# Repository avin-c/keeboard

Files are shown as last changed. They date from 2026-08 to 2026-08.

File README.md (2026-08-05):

# Keeboard
my custom 65% mechanical keyboard

total time spent: 12.75 hours

## Bill Of Materials 

| Item  | Quanity | Cost | Source |
| --- | --- | -- | -- |
|  15mm x 1.5mm Rubber Pads | 4  | $3.89 | [AliExpress](https://www.aliexpress.com/item/1005009215190070.html) |
| Content Cell  | Content Cell  | -- | -- |

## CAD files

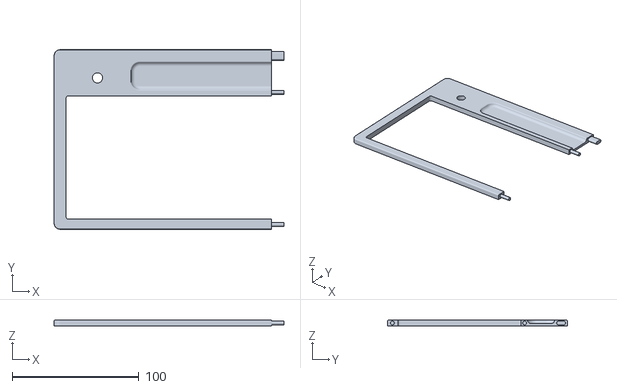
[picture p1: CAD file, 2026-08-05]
keeb-3d-files/top-left-case.stl
181.5 x 141.8 x 5.00

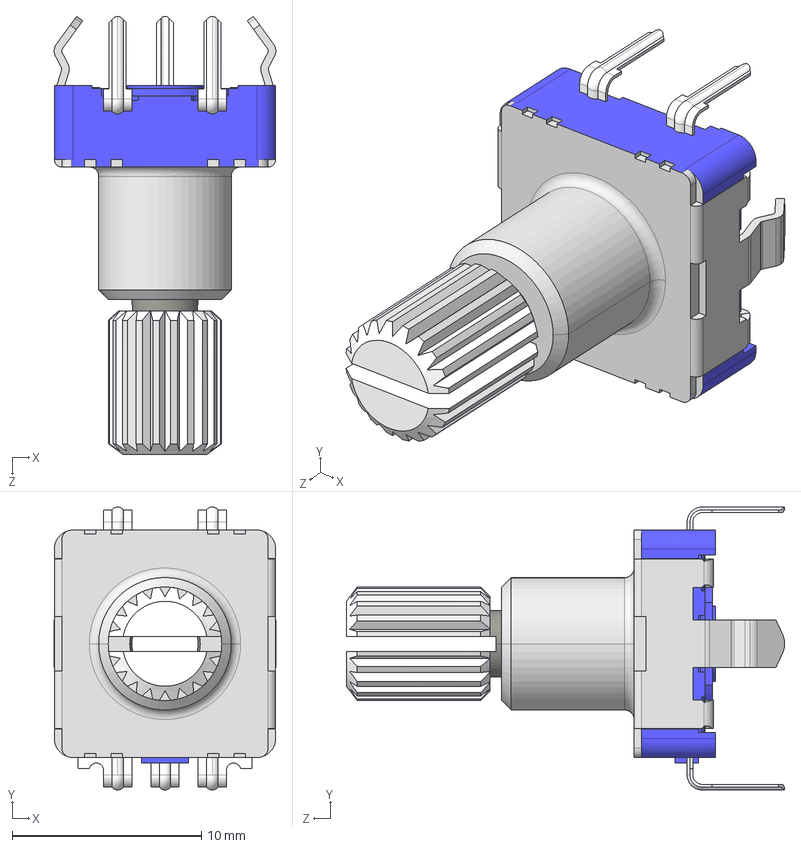
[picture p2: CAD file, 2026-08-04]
keeb-kicad/Assets/EC11 Rotary Encoder Dode Switch-15mm .STEP
11.7 x 15.0 x 23.2 mm

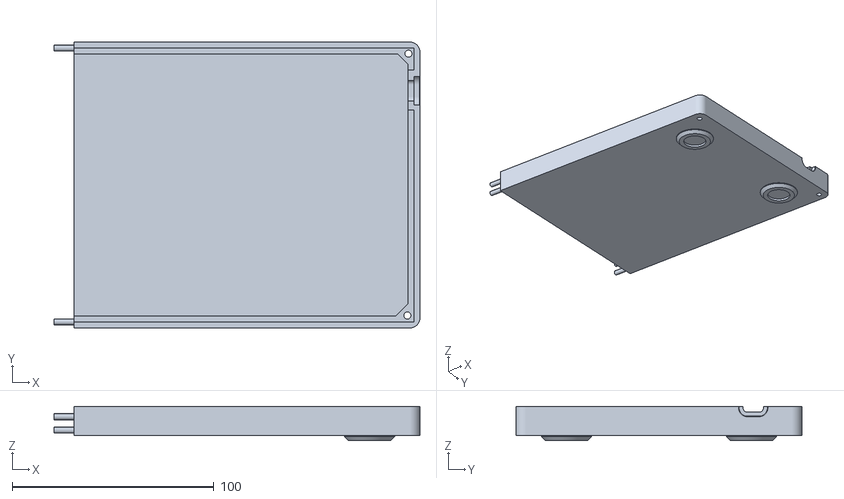
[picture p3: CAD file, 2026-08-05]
keeb-3d-files/left-bottom-tray.stl
181.5 x 141.8 x 17.1

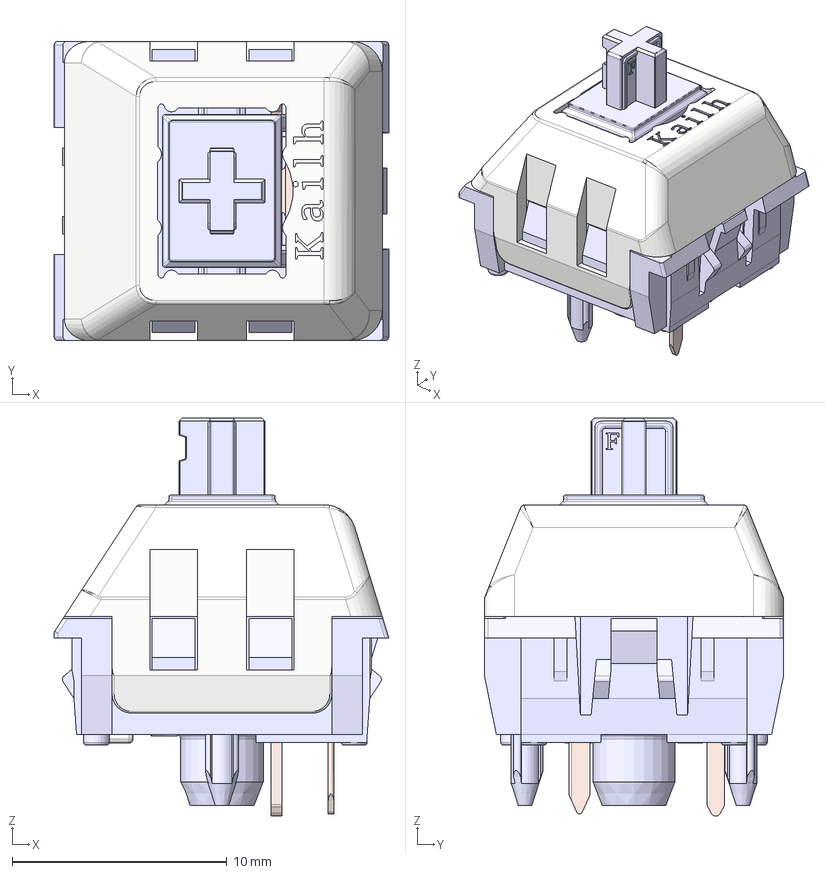
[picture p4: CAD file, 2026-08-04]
keeb-kicad/Assets/Kailh Polia.step
15.6 x 14.0 x 18.5 mm
Housing
ThickContact
SpringContact
Stem
Lid

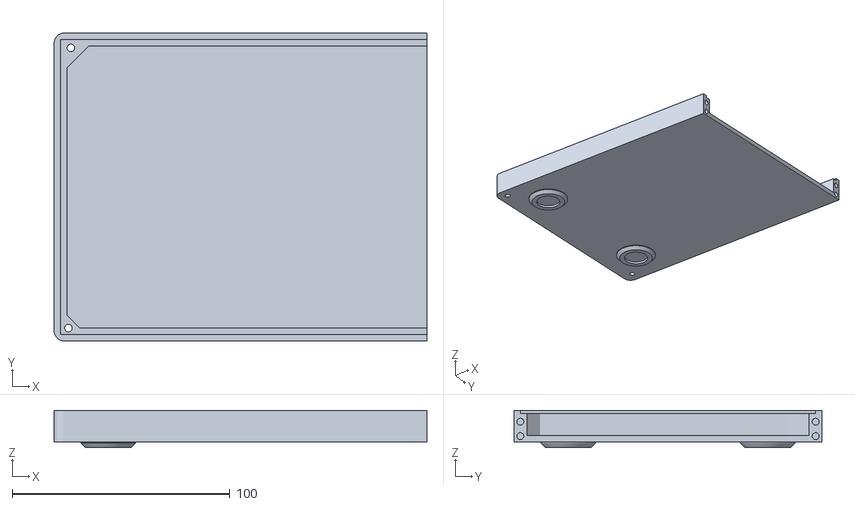
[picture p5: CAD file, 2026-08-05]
keeb-3d-files/right-bottom-tray.stl
171.5 x 141.8 x 17.1

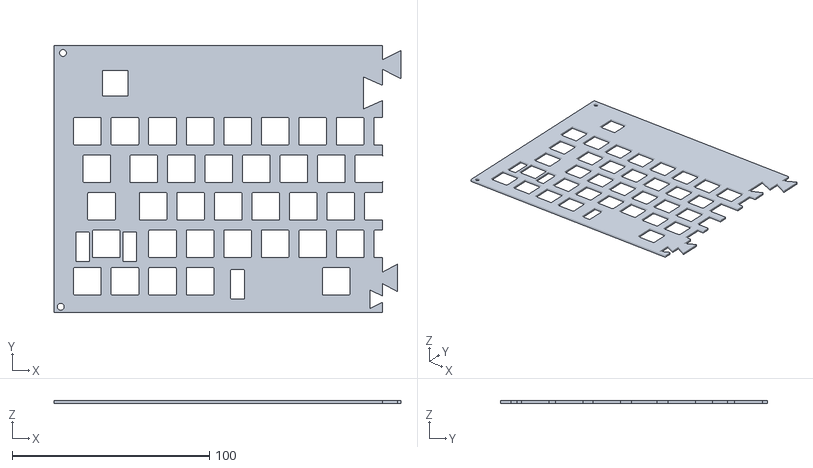
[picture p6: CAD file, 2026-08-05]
keeb-3d-files/right-plate.stl
176.1 x 135.4 x 1.50

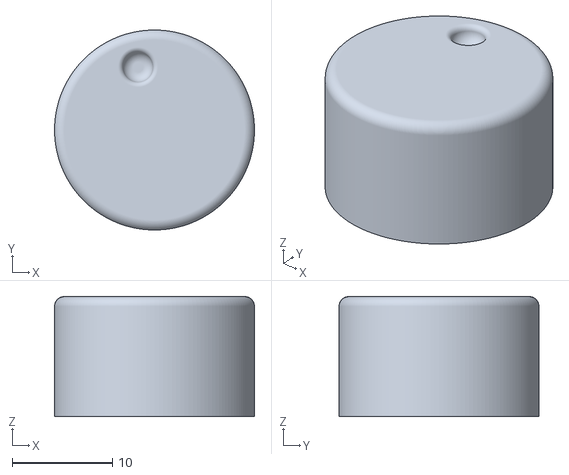
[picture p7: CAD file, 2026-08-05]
keeb-3d-files/knob.stl
20.0 x 20.0 x 12.0

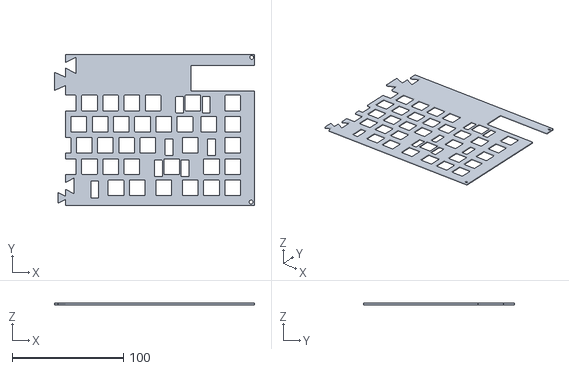
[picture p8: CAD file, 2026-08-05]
keeb-3d-files/left-plate.stl
179.6 x 135.4 x 1.50

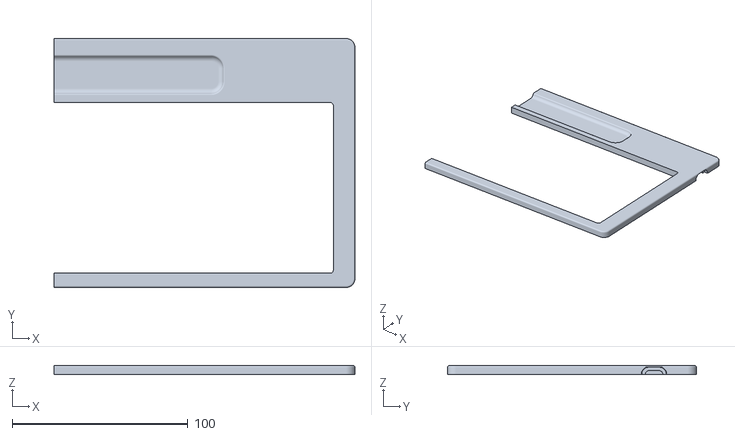
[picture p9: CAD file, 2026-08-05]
keeb-3d-files/top-right-case.stl
171.5 x 141.8 x 5.00

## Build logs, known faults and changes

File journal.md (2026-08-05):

## Journal
### August 2 
(1 hour)
Planned out my 65% keyboard using excalidraw. Decided to add a rotary encoder in the top left for volume, due to the lack of a function row. The Raspberry Pi Pico is located in the top right to allow for USB-C port on top right corner. 

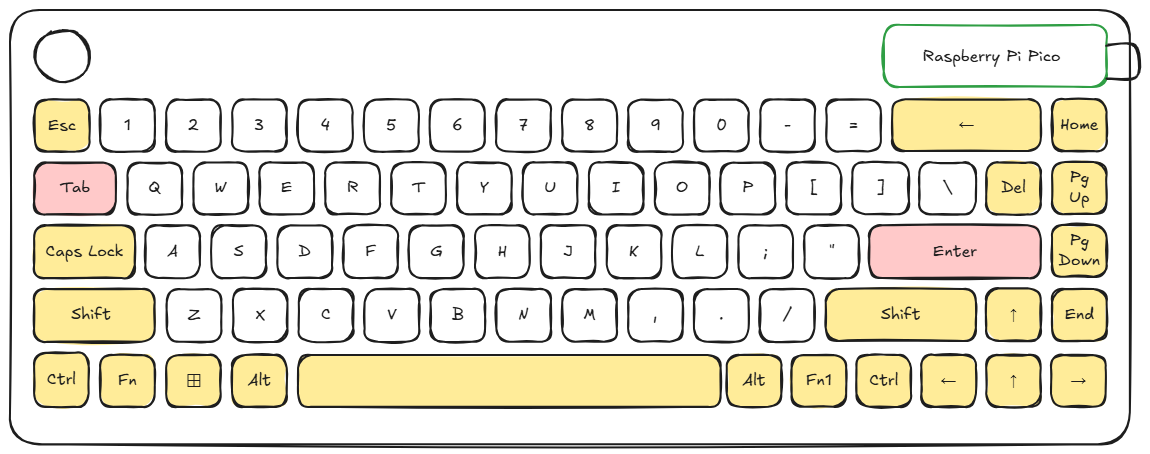
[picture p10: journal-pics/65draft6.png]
layout of 65% keyboard with rotary encoder in top left and pico in top right


(1 hour) Set up KiCad and installed [marbastlib](https://github.com/ebastler/marbastlib) library. Also created the below matrix for my keyboard to plan where my rows and columns will go, and where each switch will connect to. I ended up with a 16x5 matrix grid, which uses 21 pins and handles 80 keys of which my keyboard uses 70 of. 

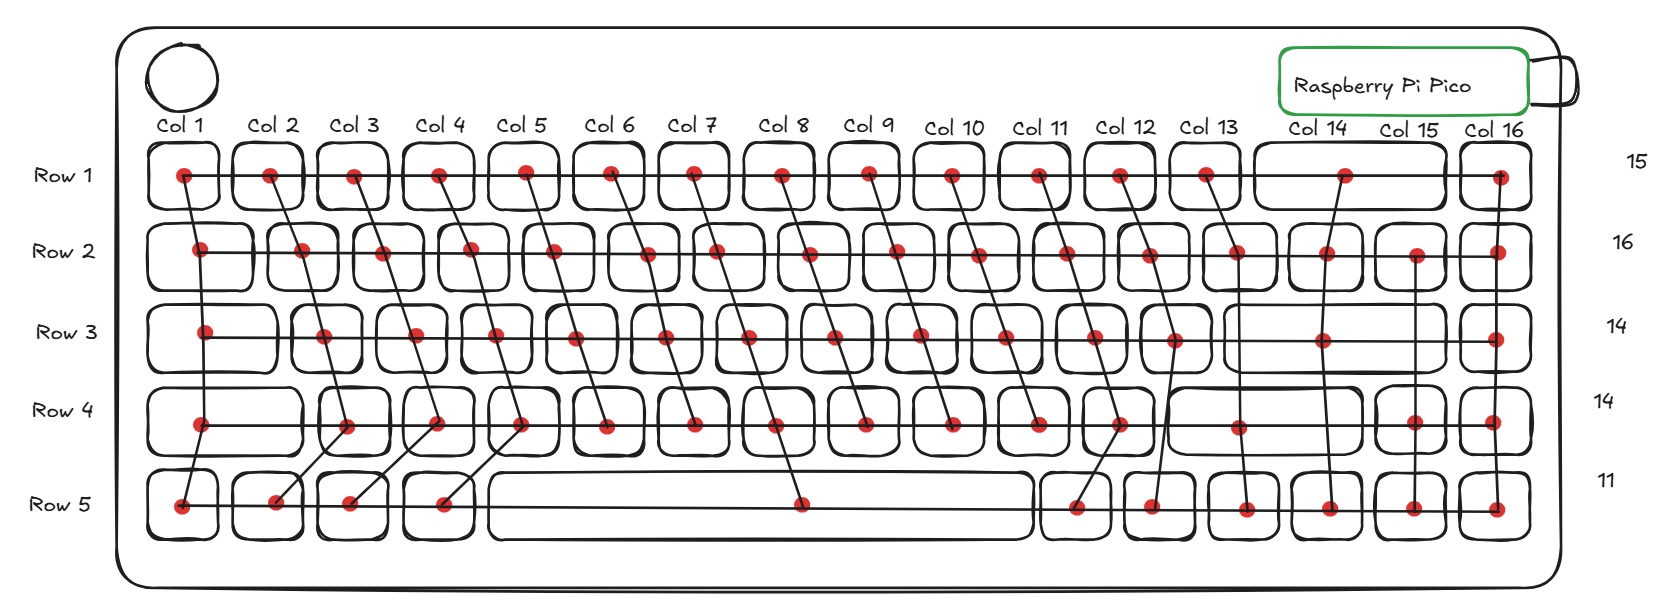
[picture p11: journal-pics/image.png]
Keyboard matrix of my keyboard with 16 columns and 5 rows. Each of the 70 switches is highlighted with a red dot


(1.5 hours) Designed schematic on KiCad, following my layout in the diagram above. Added the Pico, switches, diodes, stabilizers, and rotary encoder. Arranged each switch-diode set into a matrix following the layout of the matrix above. Then connected each row/column wire to the Pico using net labels. Also connected the Rotary Encoder to the Picousing net labels and GND symbols. Finally, annotated everything using the automatic annotation tool. Also checked that the connections were working with the highlight net label function and confirmed that everything was properly connected.

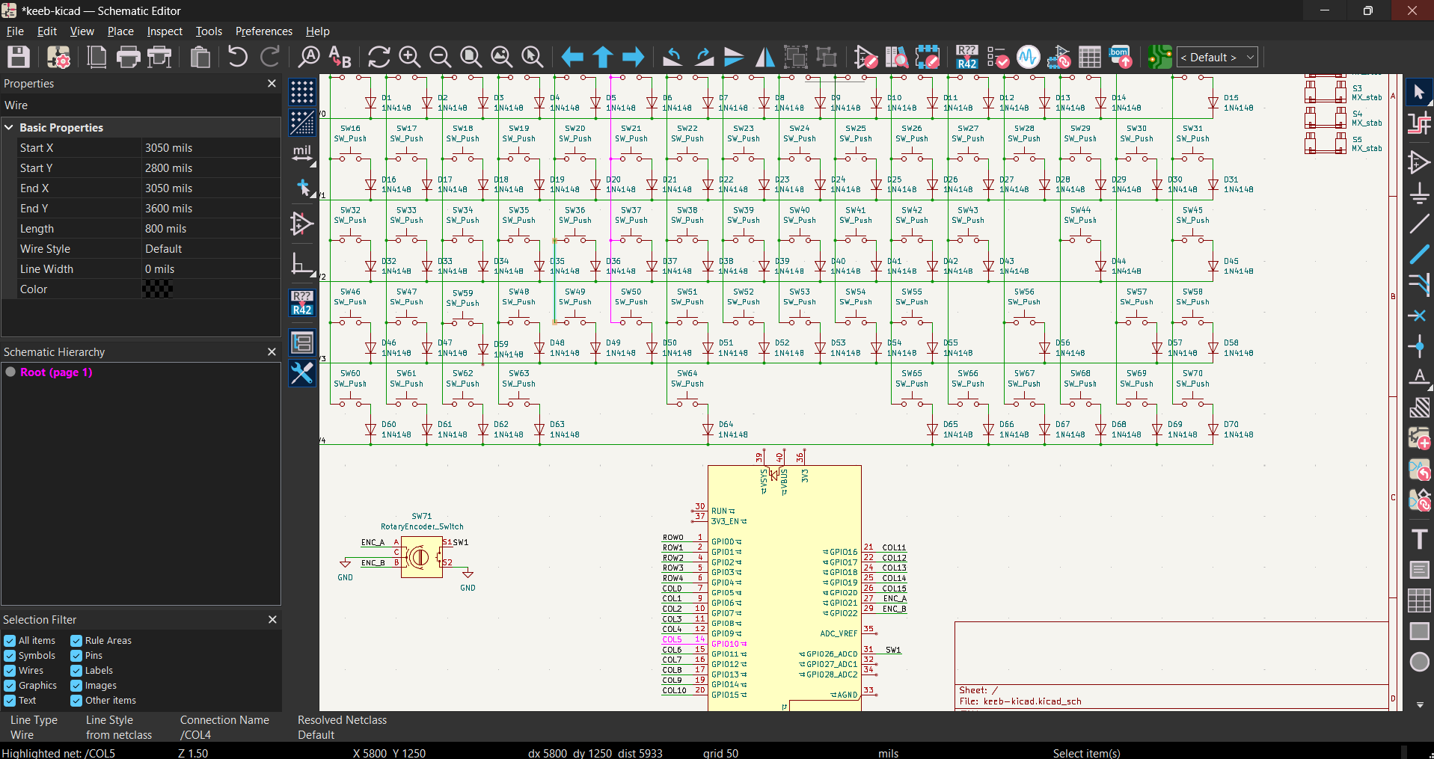
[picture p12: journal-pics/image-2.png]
Screenshot of my KiCad window with my schematic finished with my switches and diodes in proper positions within the matrix and the matrix rows/columns connected to the Raspberry Pico. Also have the stabilizers off to the side for the footprint and the rotary encorder connected as well to the Pico


(0.5 hours) Assigned footprints to my components. Took a while because I had to find out what kind of footprint the rotary encoder uses, which I learned was a RotaryEncoder_Alps_EC11E-Switch_Vertical_H20mm footprint in KiCad. Also had to configure each stabilizer footprint to the correct size, but there were some that were a little smaller: 2.25u instead of my 2.5u so I will see how that works out later. 
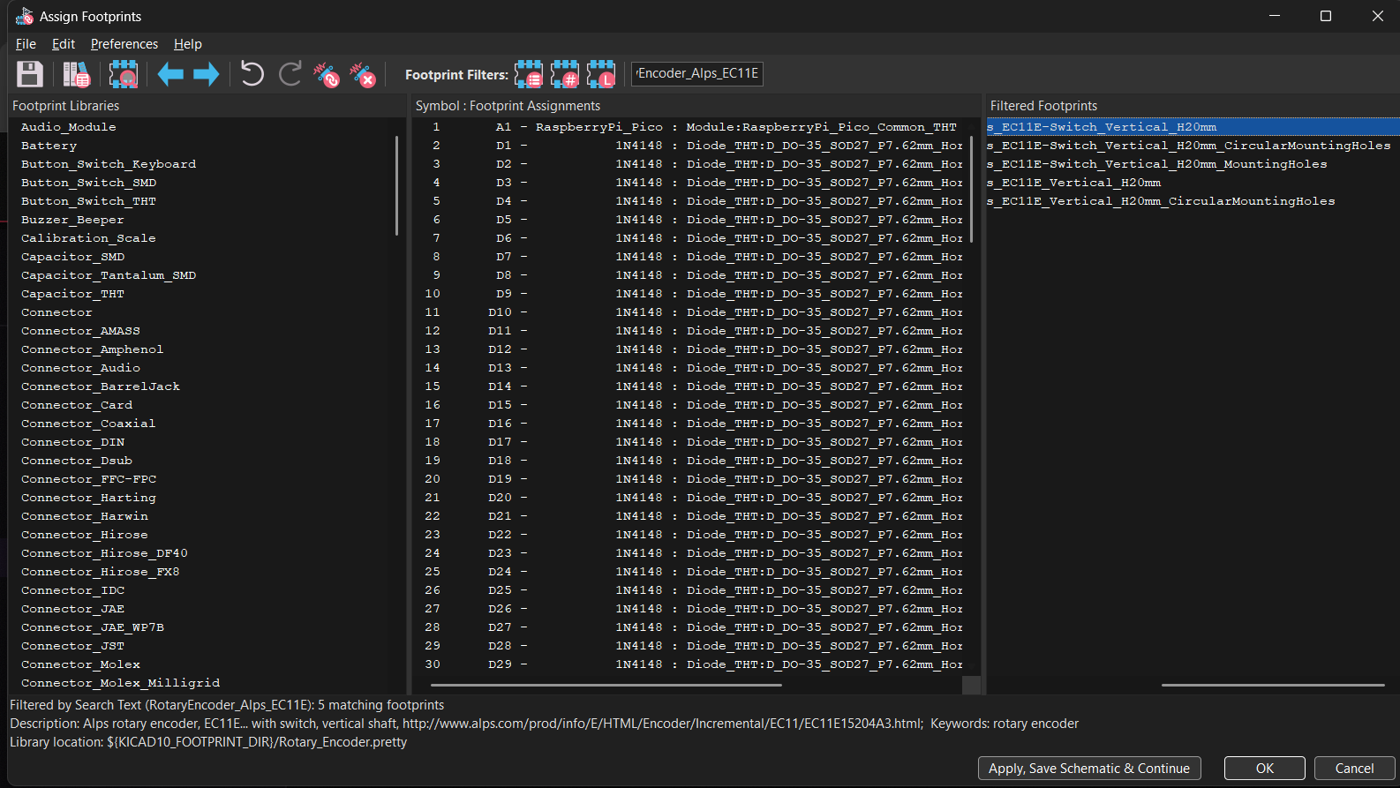
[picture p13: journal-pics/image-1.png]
Screenshot of my footprint assignment popup


(1.5 hours) Started to do the PCB from the schematic. Very very difficult, had to restart several times. I can't seem to get the grid working because of the nonortholinear layout, it doesn't cooperate very well, and I have to manually set every single switch. Anyways, I just finished debugging some minor math error, and I reconfigured the layout becasue 2.5u stabilizers aren't allowed apparently, so I just made the whole keyboard 0.25u wider. Then, I moved everything and readjusted the whole keyboard so now I have finished the top two rows of the keyboard, but only the switches. Hopefully, progress will ramp up soon, because this is getting very tedious.

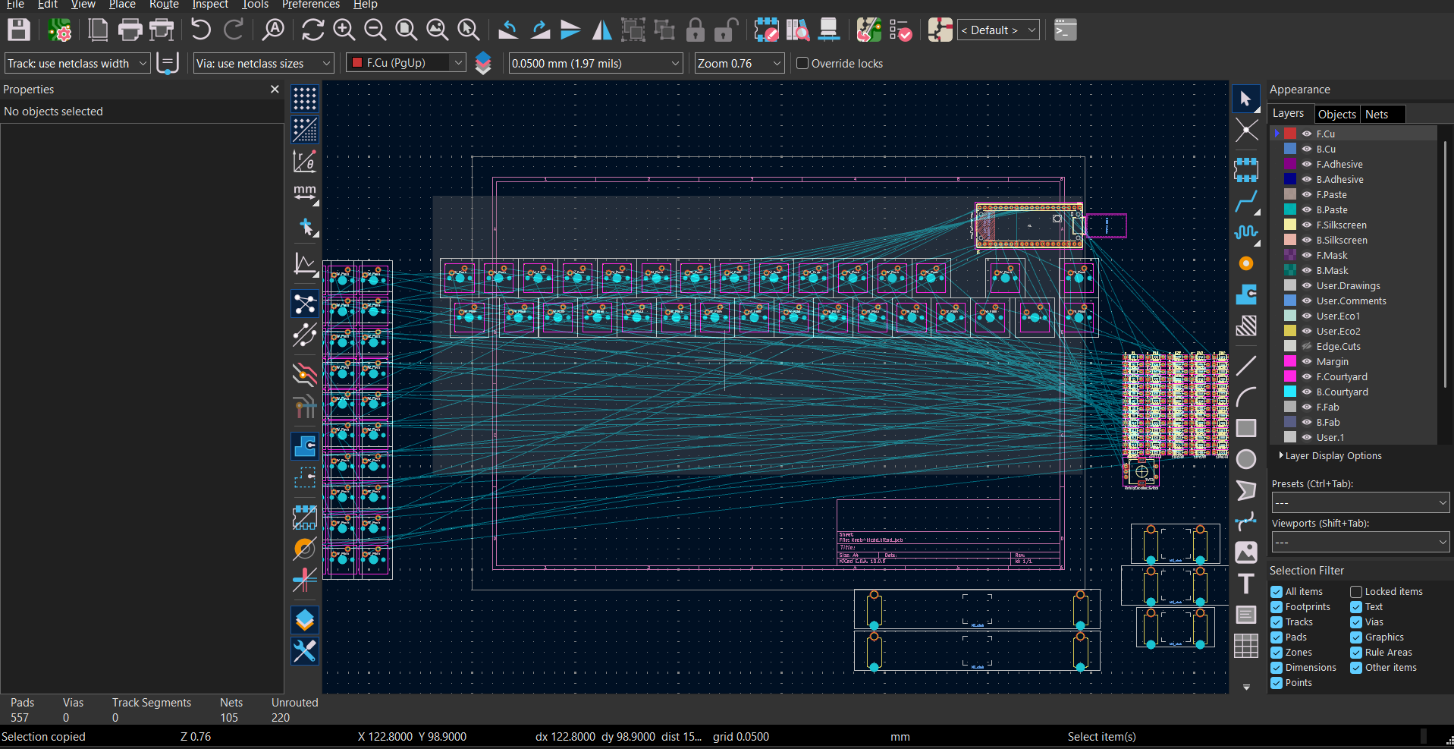
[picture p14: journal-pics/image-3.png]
Two rows of PCB switches done


(1.25 hours) Finished up the rest of the keyboard switches, and had to make further resizing changes and just lots of adding and subtracting to get the proper locations of each of the switches. Maybe I should've done an ortholinear keyboard instead, haha. Anyways, now it is configured with an additional 0.25u in width as there are no 2.5u stabilizers in the library. So there are some keys with like an extra 0.25u like the right control button, enter key etc..Anyways, this pcb assembly really tested my patience and was much more difficult than I thought it would be. The initial setup was pretty overwhelmed with all the lines connected everywhere but I think I'm slowly getting the hang of it. 

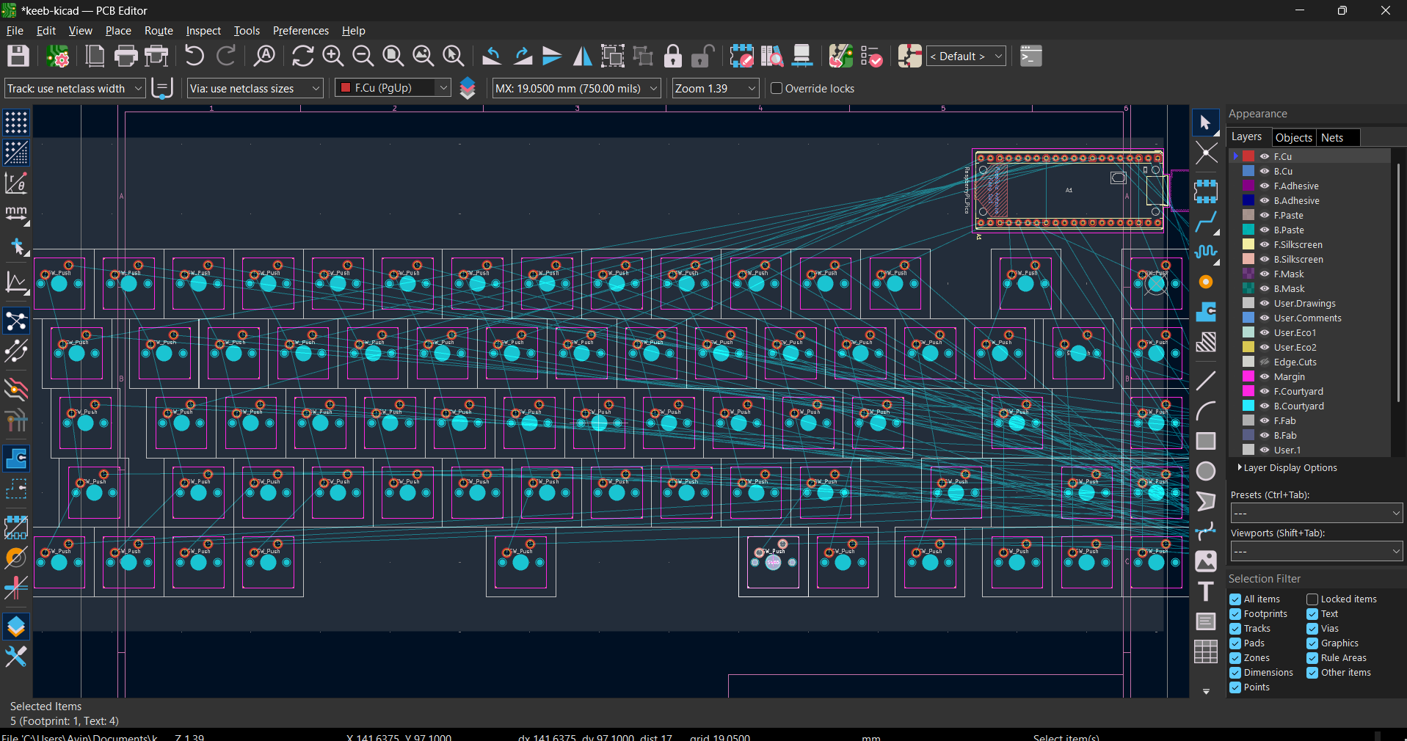
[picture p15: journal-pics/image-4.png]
Screenshot of completed keyboard switches located. Lots of lines and pcb stuff.


### Aug 3 
(1.25 hours) Woke up bright and early to continue working on this project! I have finished the diode placements, placing each diode on the right edge of the switch, roughly in the middle. I had to fix some rerouting errors leftover from the schematic because the schematic annotation was wrong and that led to the diode naming to be wrong, so I had to fix that up before placing the diodes. Then, I placed the stabilizers on the exact position as the switches. I also placed the rotary encoder in the top left, as I had planned in the original layout. Then, I also resized the PCB edge so that it would fit everything I had placed into it. Overall, it is now looking pretty clean and I am very happy with how it looks, as I move onto the next steps. 

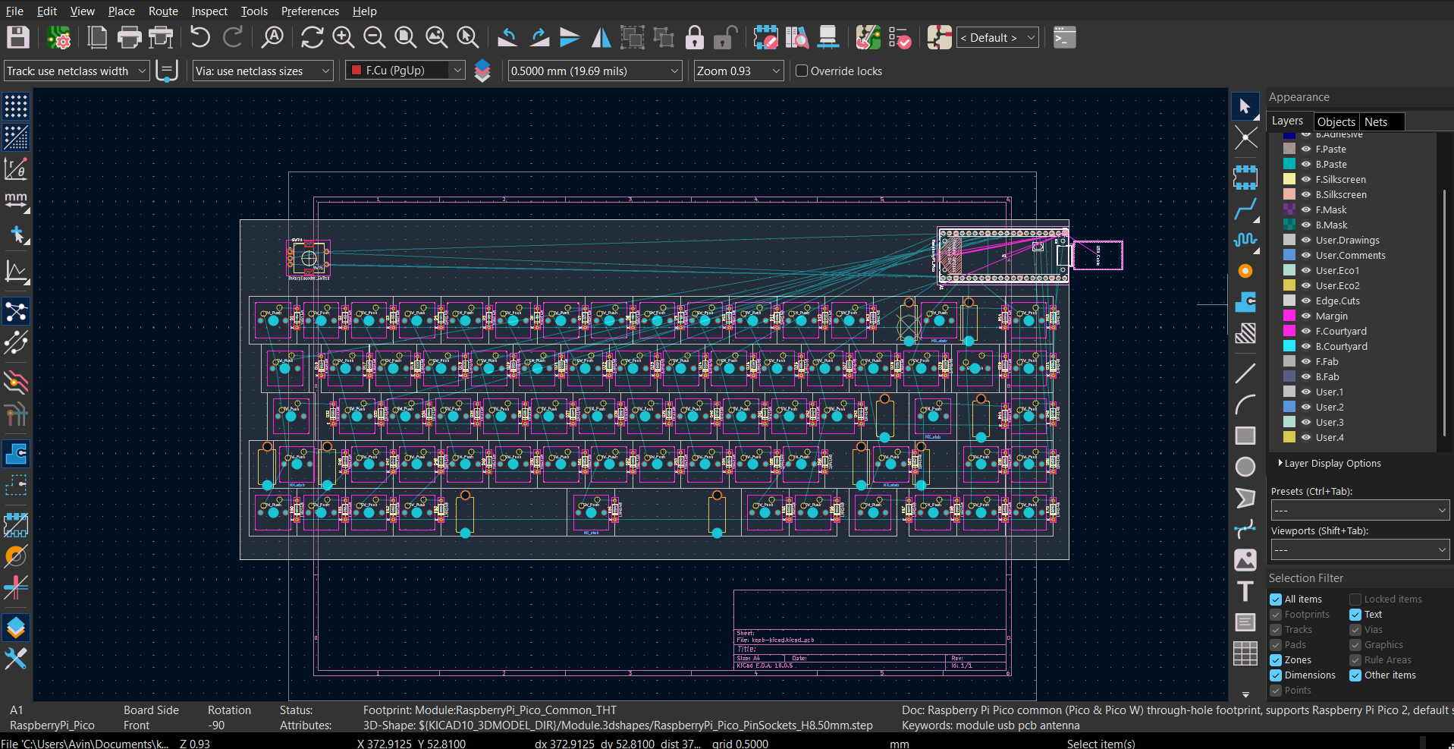
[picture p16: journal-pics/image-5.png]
Completed PCB footprint placements with diodes, switches, stabilizers, rotary encoders, etc...


(1 hour) Started doing the route tracing, and finished the front copper side. A lot more difficult than I imagined, because my original Pico connections were not very optimized for this, but after rearranging everything I figured out a way to get them placed neatly. Still only finished the front side, as I had to restart once realizing midway through that it wouldn't work, but now I think it is ok. My front copper currently has the rotary encoder connections and the row connections. And I plan on placing the column routes on the back side of the PCB. 

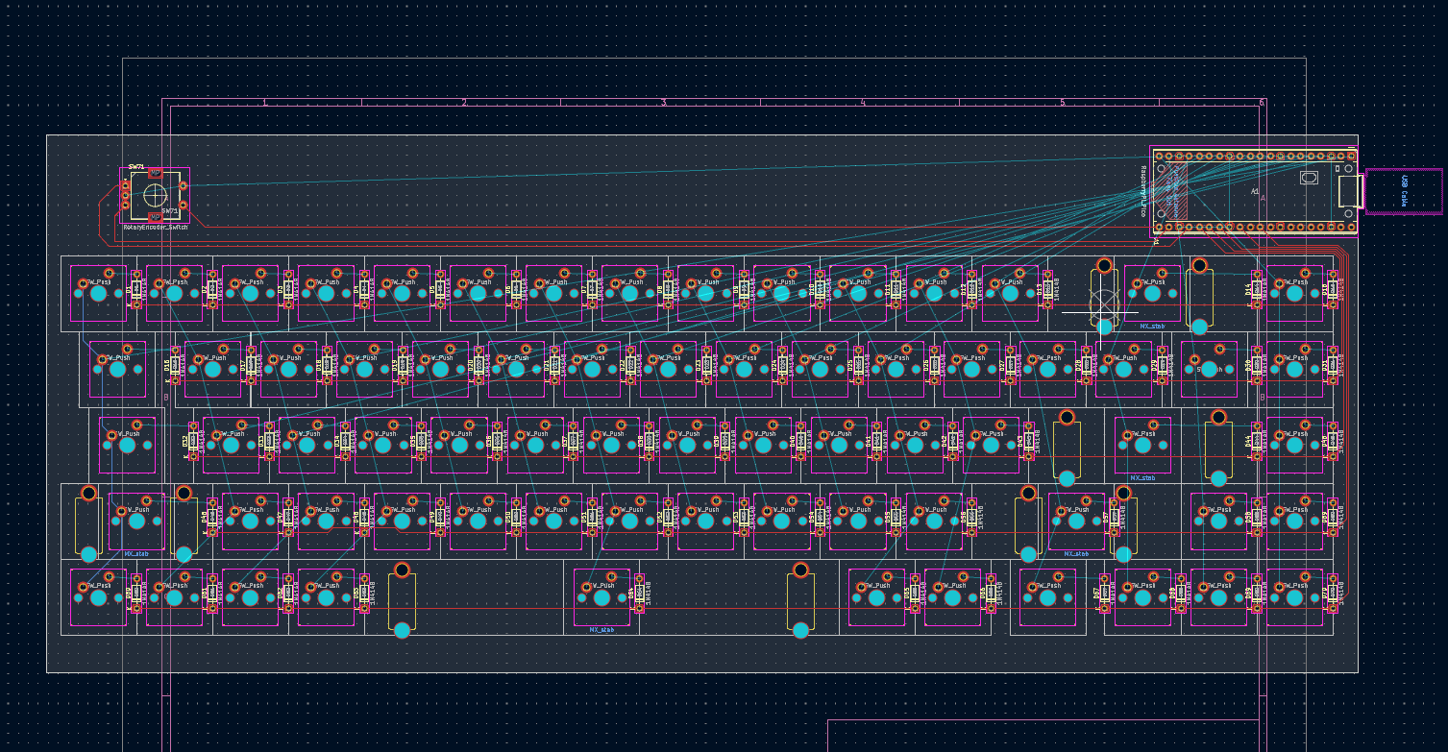
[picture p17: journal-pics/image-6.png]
Finished front (red) copper route tracing on keyboard PCB


(1 hour) Finished all the front and back route tracing, with the rotary encoder as well. Started to become pretty intuitive and I started to understand more of how it was connecting back to the schematic. While finishing all the route tracing I also had to rewire some pins and change the board size and Pico positioning to accomodate all the routes, but luckily I managed to get it working. After that, I filled in the front and back copper with ground fill, and now I am at "Unrouted: 0"! Hopefully this means that I am almost done. 

Completed route traces screenshot:
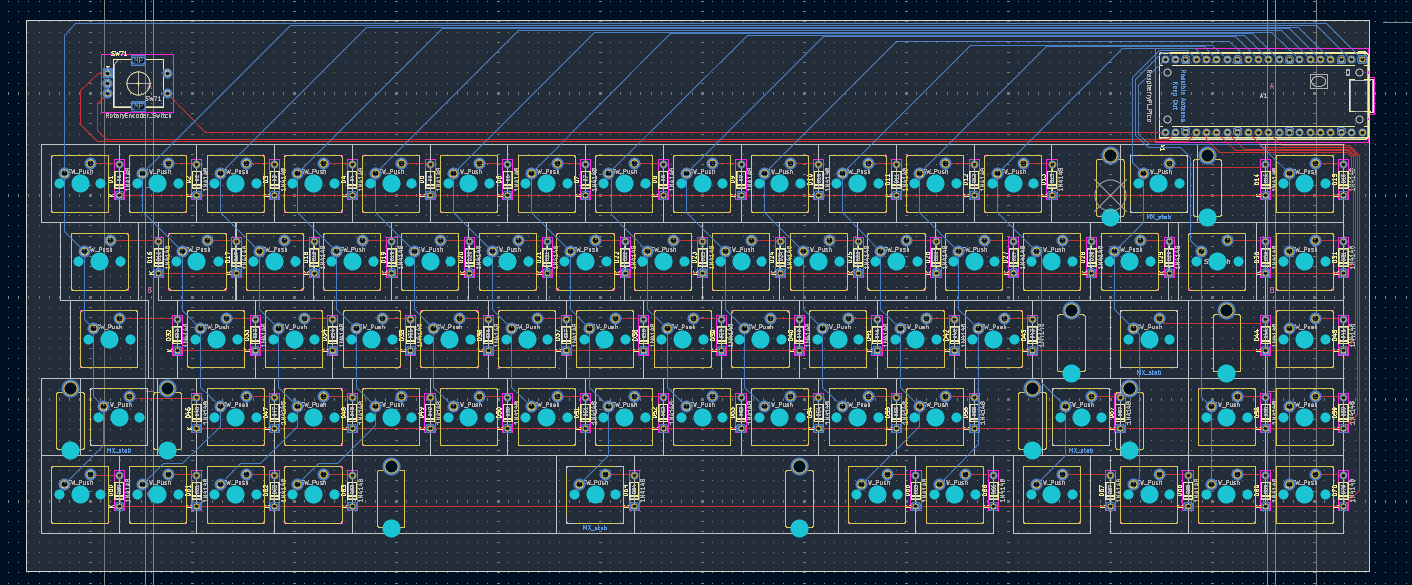
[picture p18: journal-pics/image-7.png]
All route traces completed except for ground which I have hidden in this picture

Completed route traces + ground fill:
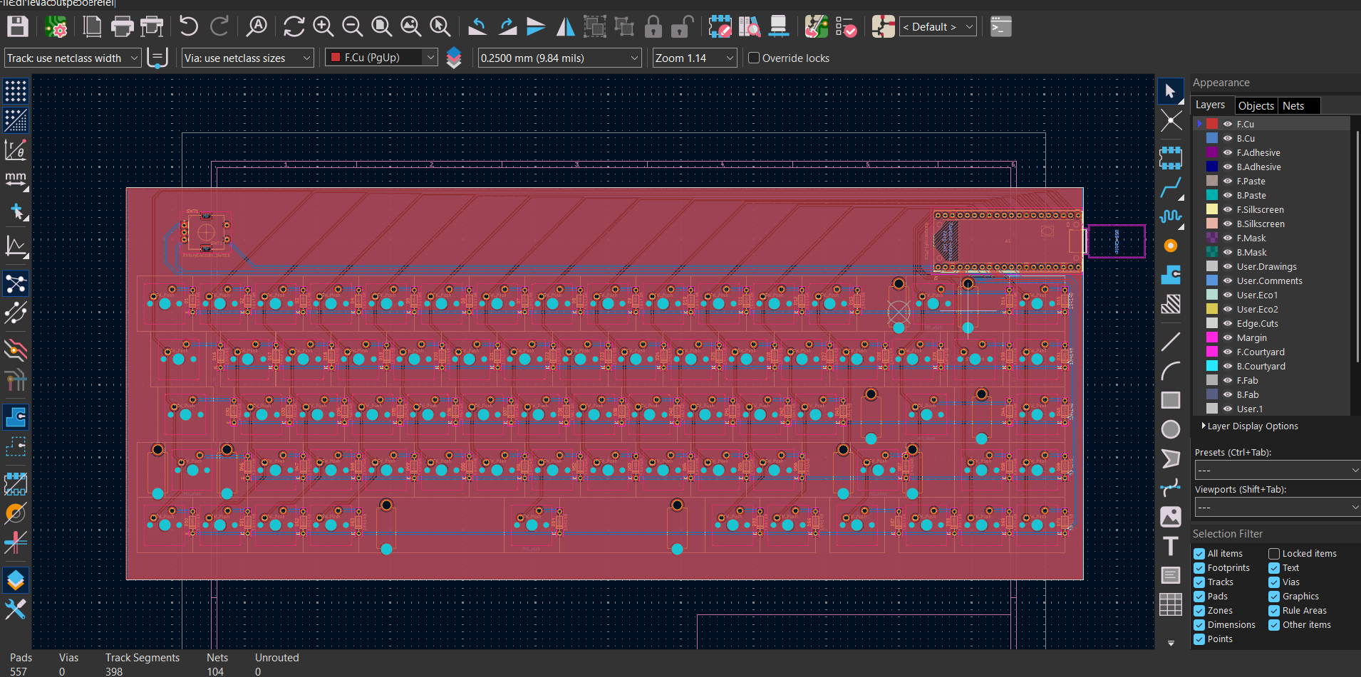
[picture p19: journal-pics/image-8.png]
Front copper PCB with red ground fill with all route traces completed


(0.75 hours) Shifted the Pico up a little bit to allow more clearance from the keyset. Completed the DRC testing and fixed everything that needs fixing. Also tested with the 3d model but I was too lazy to put them all down so I just tested one and it seemed fine. Now there should be nothing wrong with any of the connections, only some couple minor warnings, like the silkscreen being clipped off of the board edge. Next step will be exporting the gerber files, which I have done. The compressed zip folder now includes all the gerber and drill files. 

(1 hour) Started working on the case, pretty lost in the sauce. I wanted to make a sandwich mount case, so I decided to extrude the bottom plate and start working on the bottom part of the case. And then when I finished that I was wondering where to put the plate, and then I realized that my switches in my imported step file where not on the right height, which meant I had to fix that. So I readjusted the switch height in the footprint editor. 

Point where I realized that the switches were wrong (when the switches were so low and there was no place to put a plate):
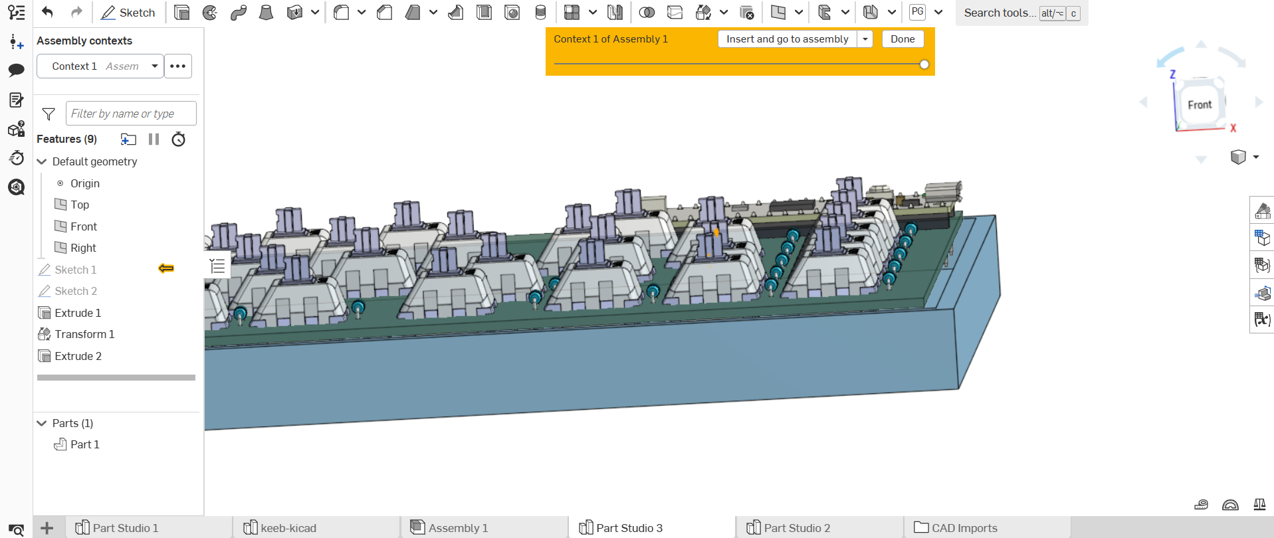
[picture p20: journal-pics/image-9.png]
Screenshot of Onshape page with case part studio and pcb assembly


Fixed 3d model that I can use later for the case making:
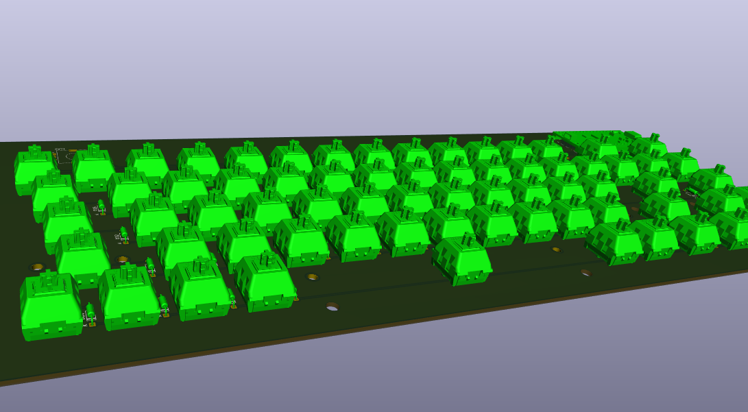
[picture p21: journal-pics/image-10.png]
Fixed 3d model of pcb with switches repositioned


(1 hour) Finalized the 3d STEP model of the pcb board. Continued working on the bottom part of the case and decided that I would have a little inset for the plate instead of just being pure sandwich, so that there aren't as many layers visible on the side profile. So the next step is to create the plate, which I am still not sure exactly how to do. Anyways thats all for today. 

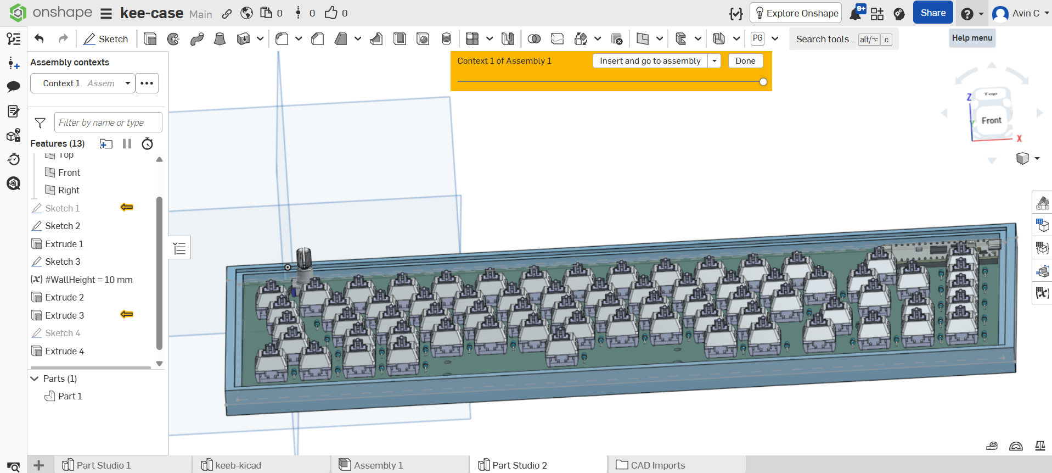
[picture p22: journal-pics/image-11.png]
Bottom tray case in onshape


### Aug 4
(1 hour | [Lapse link](https://lapse.hackclub.com/timelapse/3pcBLhghpw3_)) Continued working on the case for the keyboard, mainly focusing on the plate that seats the switches. Made a cutouts for all of my keys with linear patterns and extruded them so that I have a plate with the 14mm x 14mm cutoutts in the proper positions replicating the PCB layout. 

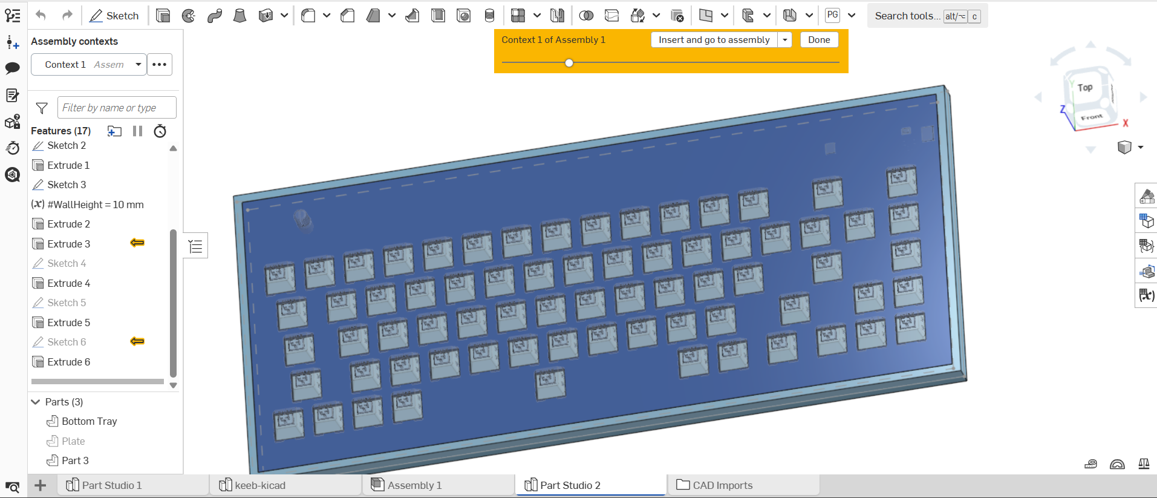
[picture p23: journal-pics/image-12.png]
Screenshot of onshape tab with my completed plate and bottom tray


(1 hour) So I thought I had it all figured out with the switches, so I did the rotary encoders, did the USB-c cutout, and even a little cutout of the Pico cuz there were some things sticking out. And then I realized I didn't put in the stabilizers! And I was wondering and wondering how to put the stablizers in because I didnt know anything about them so I asked on Slack and somebody told me that I was doing it all very inefficiently. Apparently there's already websites for making a plate instead of doing the linear pattern yourself, complete with the stabilizers and all. So I did that and was able to make a more accurate plate sketch. 

Here is my completed case before I realized that I needed stablizers:
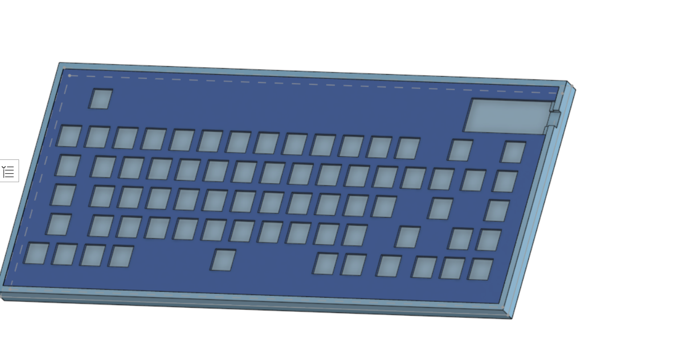
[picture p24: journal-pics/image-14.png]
Keyboard case and plate


Here is my layout made in keyboard-layout-editor:
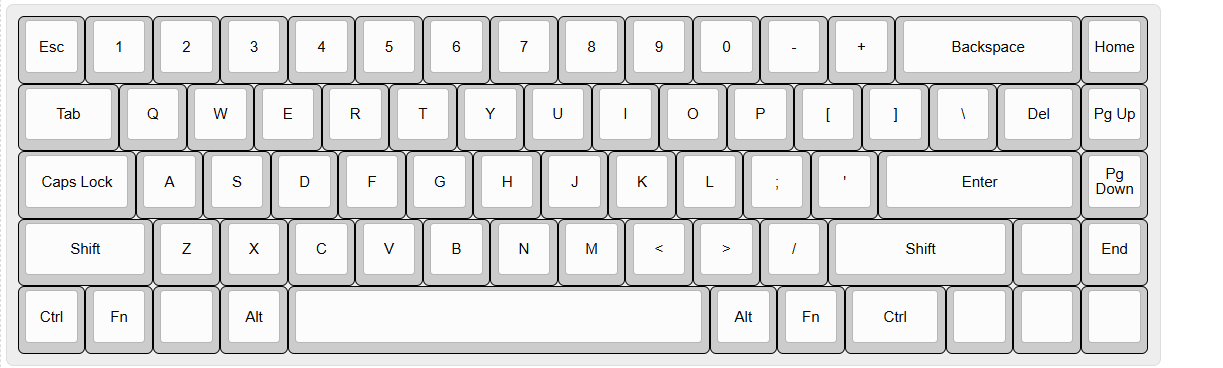
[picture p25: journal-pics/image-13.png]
Keyboard layout in keyboard-layout-editor


Here is the plate I made with my layout and the plate generator website: 

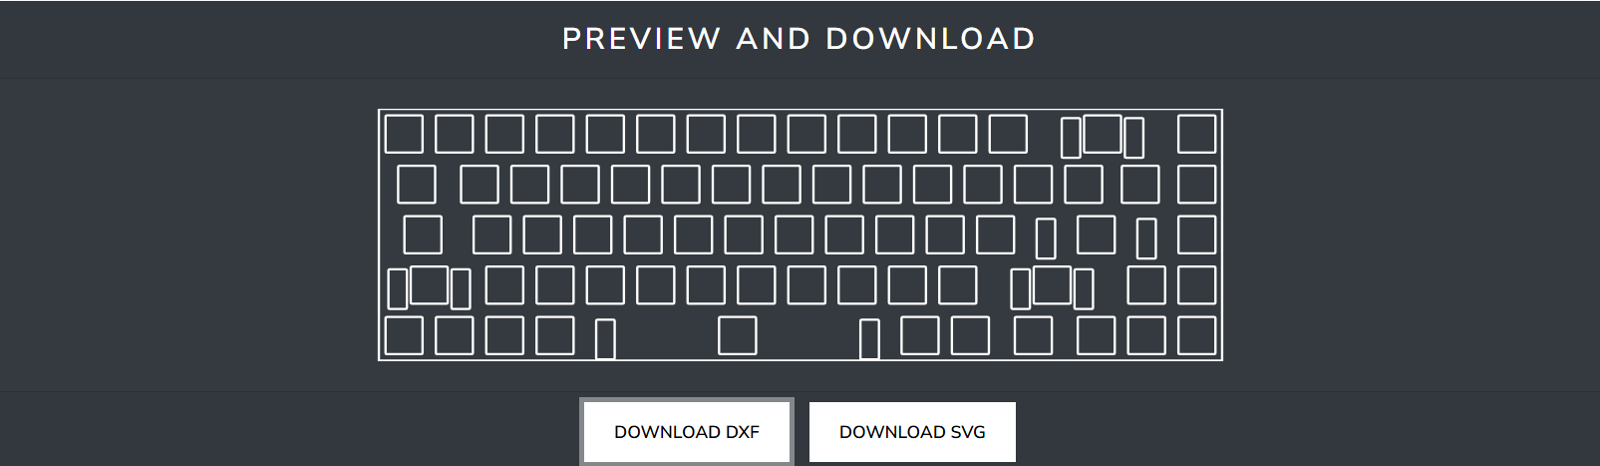
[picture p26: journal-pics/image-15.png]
Plate outline of my keyboard


(1 hour) Imported the sketch onto the Onshape Part Studio and had enormous difficulties moving it so that it matched with the existing PCB switches. I tried to drag and drop but that made them all circles or something and then I tried to select all and transform sketch but then that also made it all circles. So then finallly I had to extrude it into a 3d object and then use mate connectors to transform it, except it took FOREVER to find a suitable location for the mate connectors, so I eventually just used a corner. Anyways, I now have a plate with all the stabilizers AND switches cut out. 

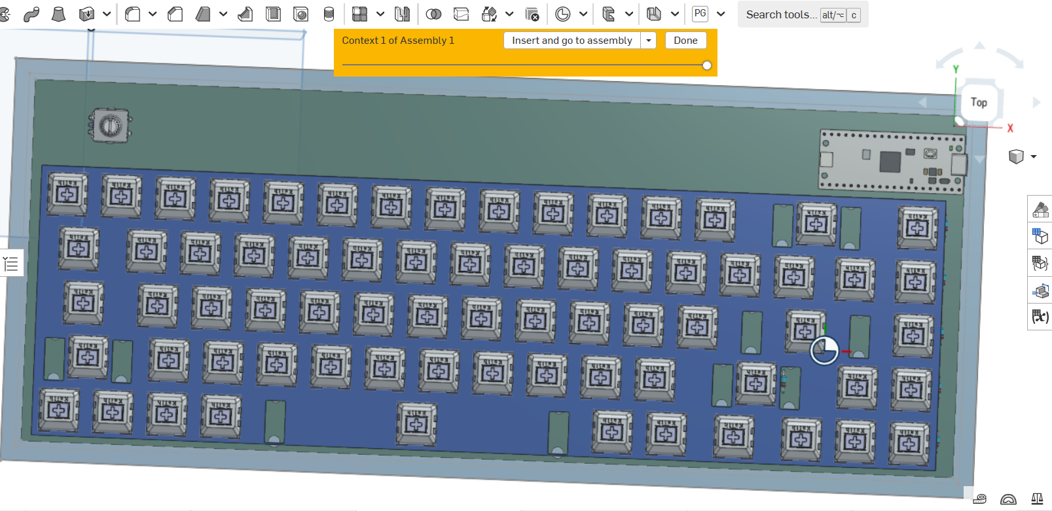
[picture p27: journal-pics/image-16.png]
Plate with both switches and stabilizers cutout in onshape


### Aug 5

(2 hours) Finished the plate and bottom tray, and added a nice cutout for the rotary encoder, Raspberry Pi Pico and USB-C port. Started working on the top case. However, I am struggling to figure out how exactly I wanted to make the top case, as I have no prior experience with it, so I decided to add the keycaps as a reference before I make it. So I am in the process of adding each keycap individually (imported from a GrabCad file of course) but it is a little bit tedious. 

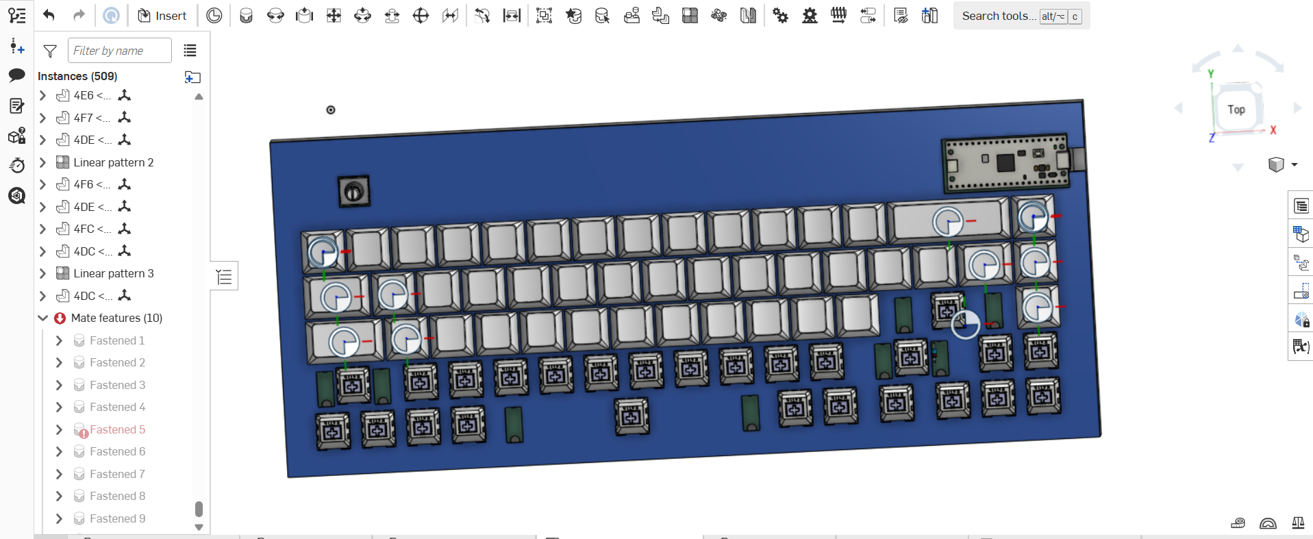
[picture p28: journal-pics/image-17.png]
Half completed case with plate completed with cutouts and keycaps half added


(0.5 hours) Update: finished up all the keycaps, now that I have the proper dimensions, I can finally get started on the top part of the case!

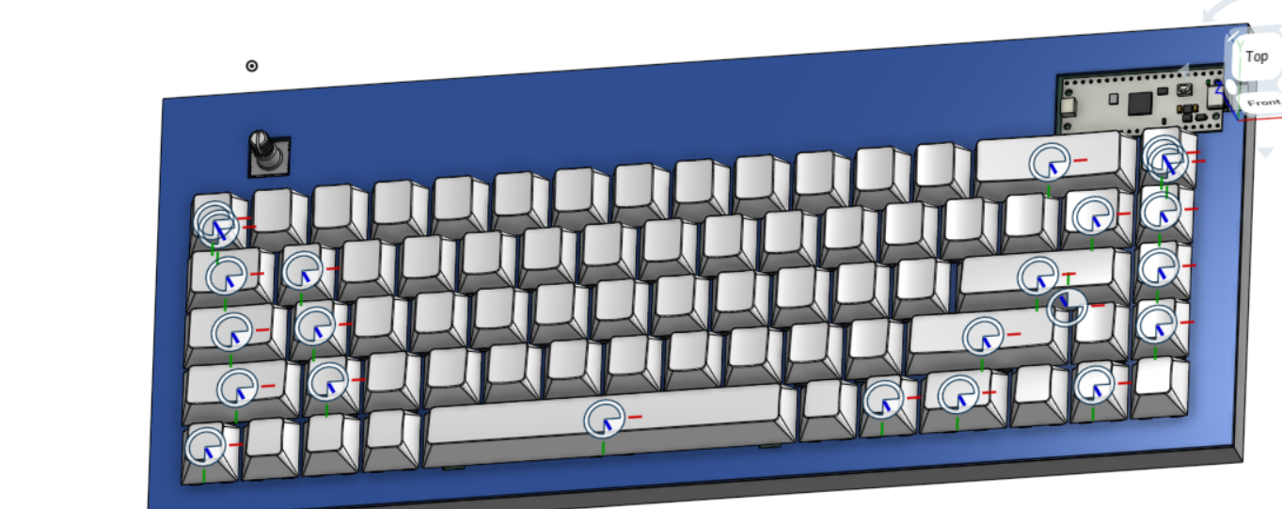
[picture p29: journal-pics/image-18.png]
Keyboard assembly with all keycaps added


(1.5 hours) Finished the top case, which includes a little border around the keycaps, a smaller circular cutout for the volume knob, and a shallow tray to take up the blank space above the top row. However, at this point, the bottom tray, plate, and top case were all the same size, meaning that it would look obvious that there would be 3 layers. So I set the plate smaller and added a wall on the bottom tray so that the plate would fit into the bottom tray, as seen below. 
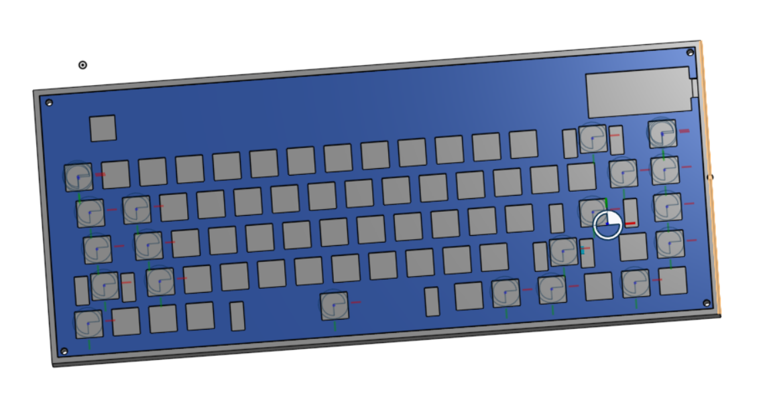
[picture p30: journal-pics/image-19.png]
Picture of the plate inset into the tray


However, by doing so, the wall was no longer thick enough to contain a full M3 screw and insert. So I had to create this triangular piece rib in all 4 corners to allow space for the boss. I will have to make corner cuts to the PCB later. Anyways, when I finished doing that I added the cylindrical bosses that would allow the top case, plate, and bottom tray to all be screwed together. 

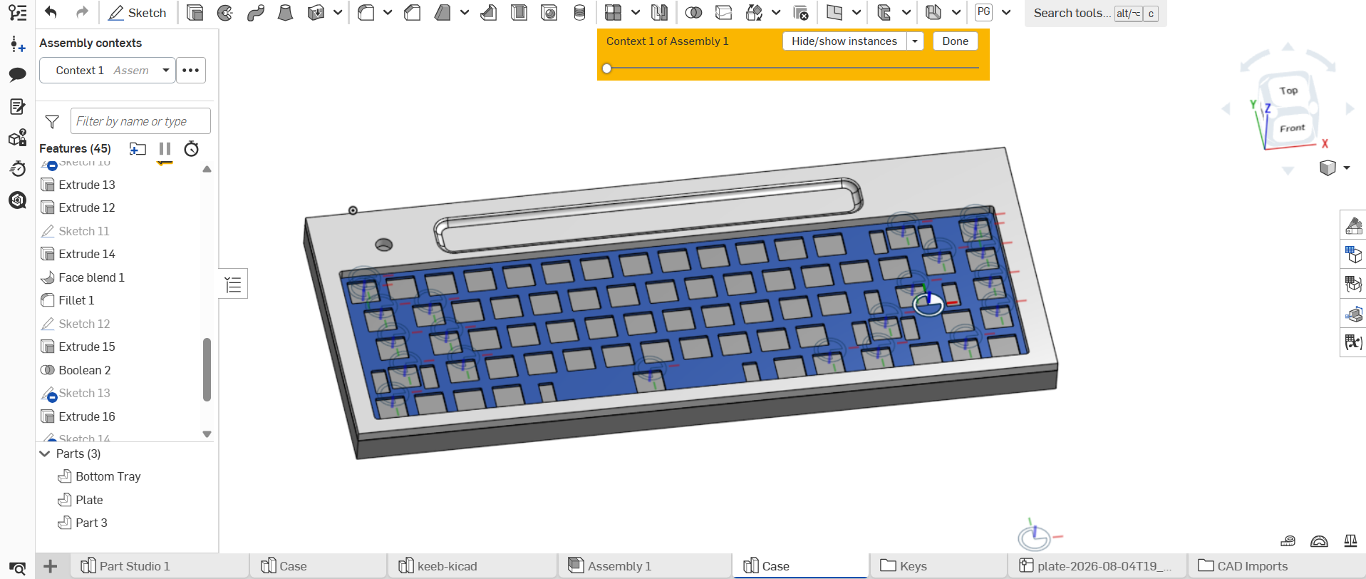
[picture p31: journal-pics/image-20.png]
Picture of the finished keyboard


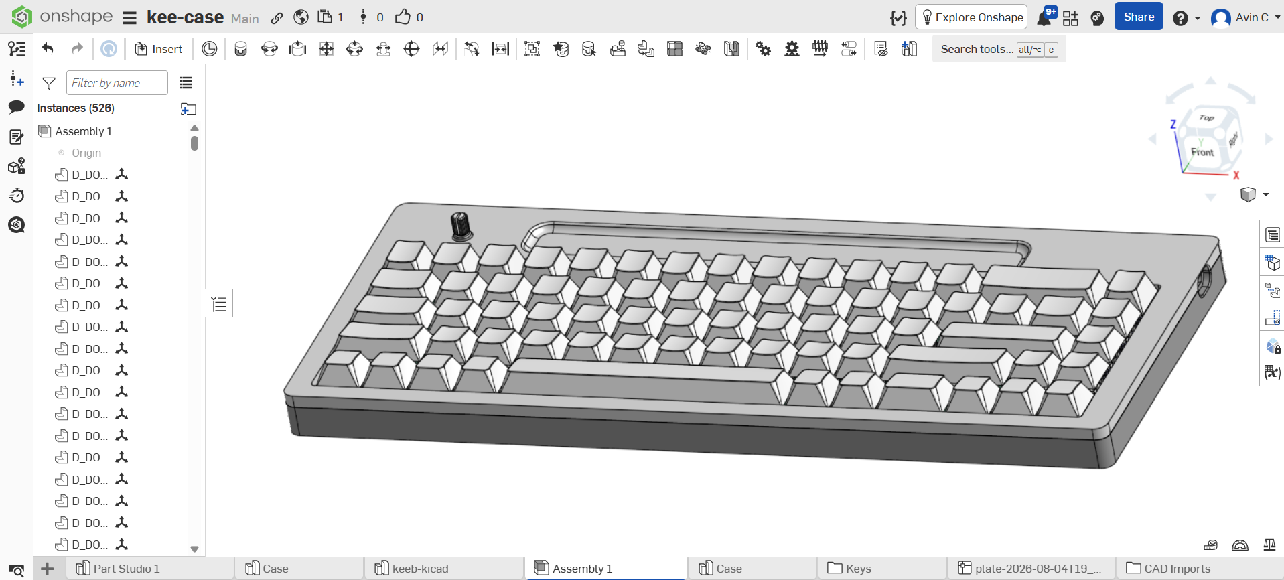
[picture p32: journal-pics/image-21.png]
Another picture of the finished keyboard with all the case parts


(1.5 hours) Refined USB-c port, added padding/legs for better base support, filleted sharp edges, and added a knob for volume control with the rotary encoder.
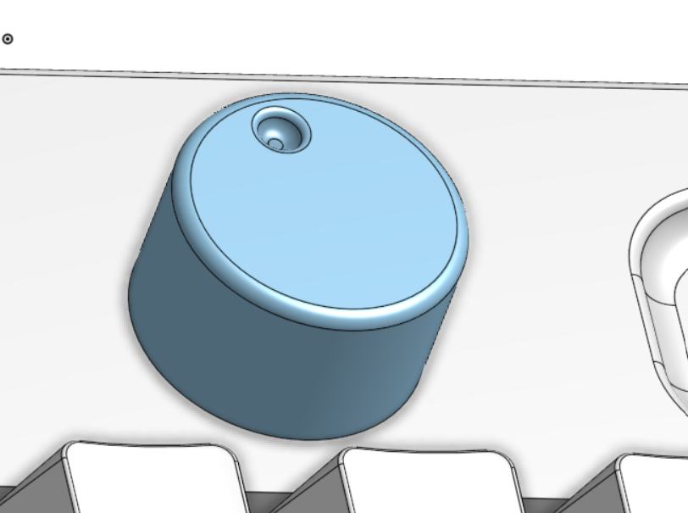
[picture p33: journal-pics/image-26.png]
Knob

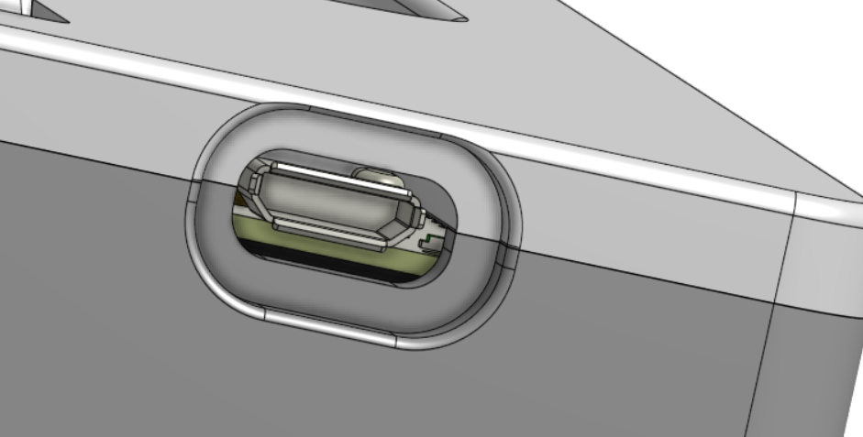
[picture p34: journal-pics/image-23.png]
USB-c port refined

Feet for the rubber pads to go into
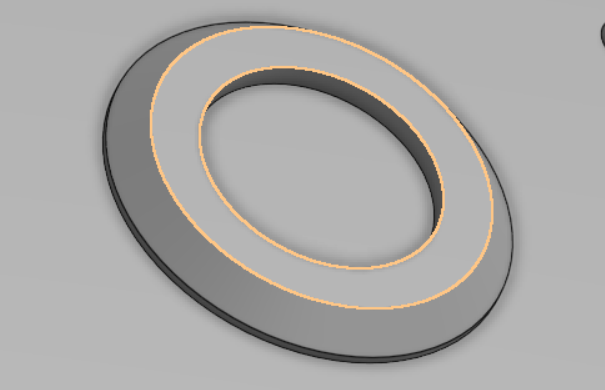
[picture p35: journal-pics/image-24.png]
Base supports

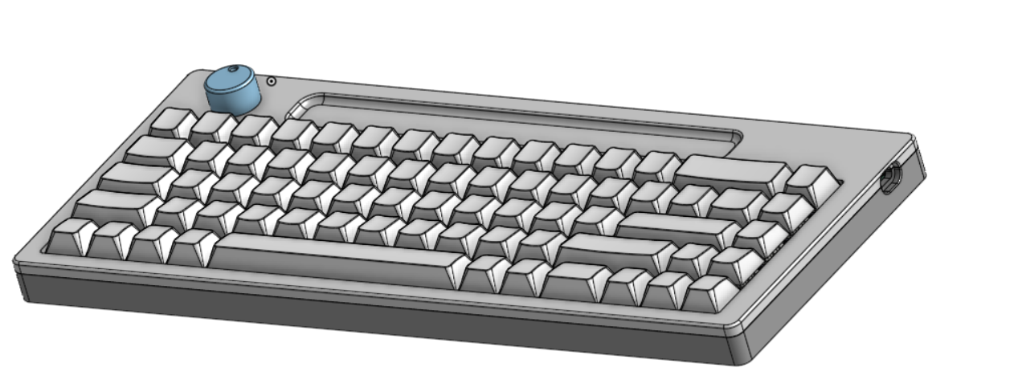
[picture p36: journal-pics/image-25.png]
Current finished render


(0.5 hours) Split the keyboard in half for printing, adding a kinda puzzle/dovetail joint for the plate as it was too thin, and then added some mortise and tenons for the top and bottom parts of the case. Hopefully there won't be a visible seam down the middle.

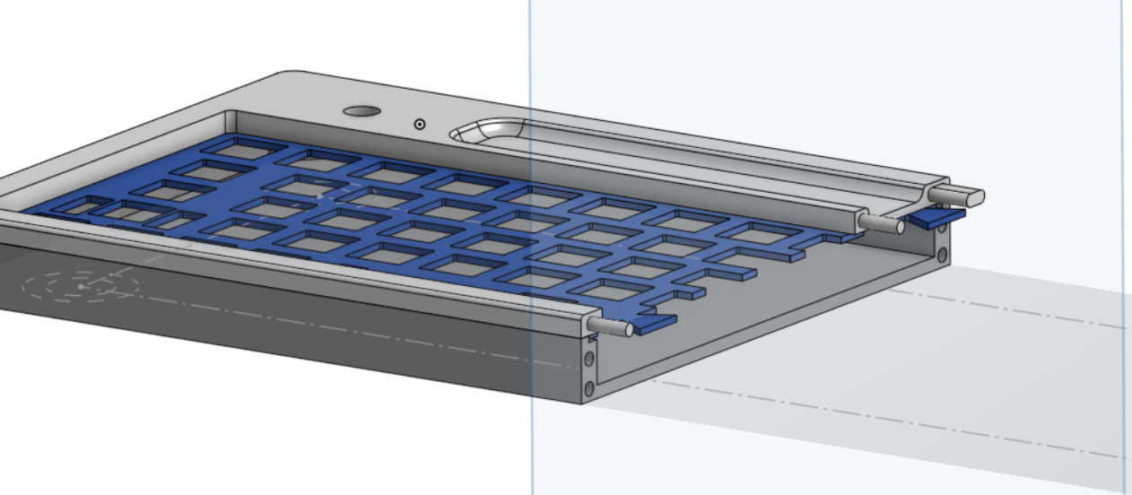
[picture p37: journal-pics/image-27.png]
Left half of keyboard

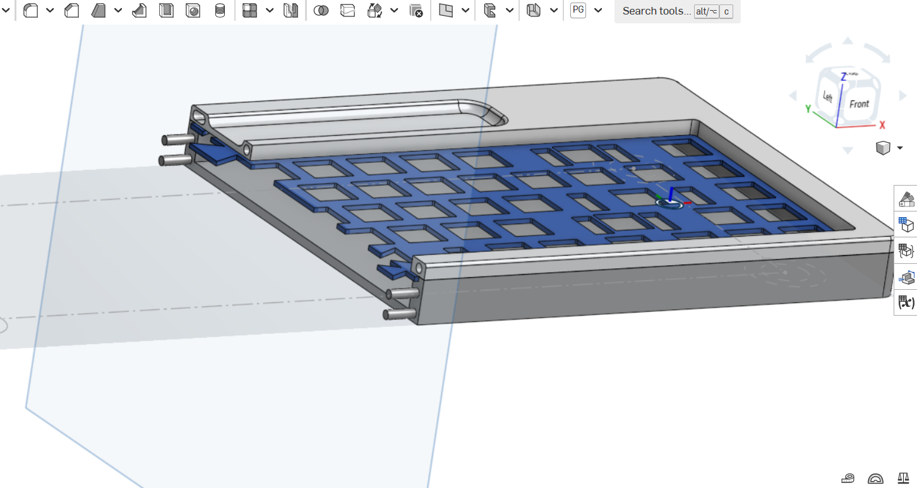
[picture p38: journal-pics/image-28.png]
Right half of keyboard


(0.5 hours) Finished up some last minute fixes and exported the file to be printed. 

Finished build!

Finished Build

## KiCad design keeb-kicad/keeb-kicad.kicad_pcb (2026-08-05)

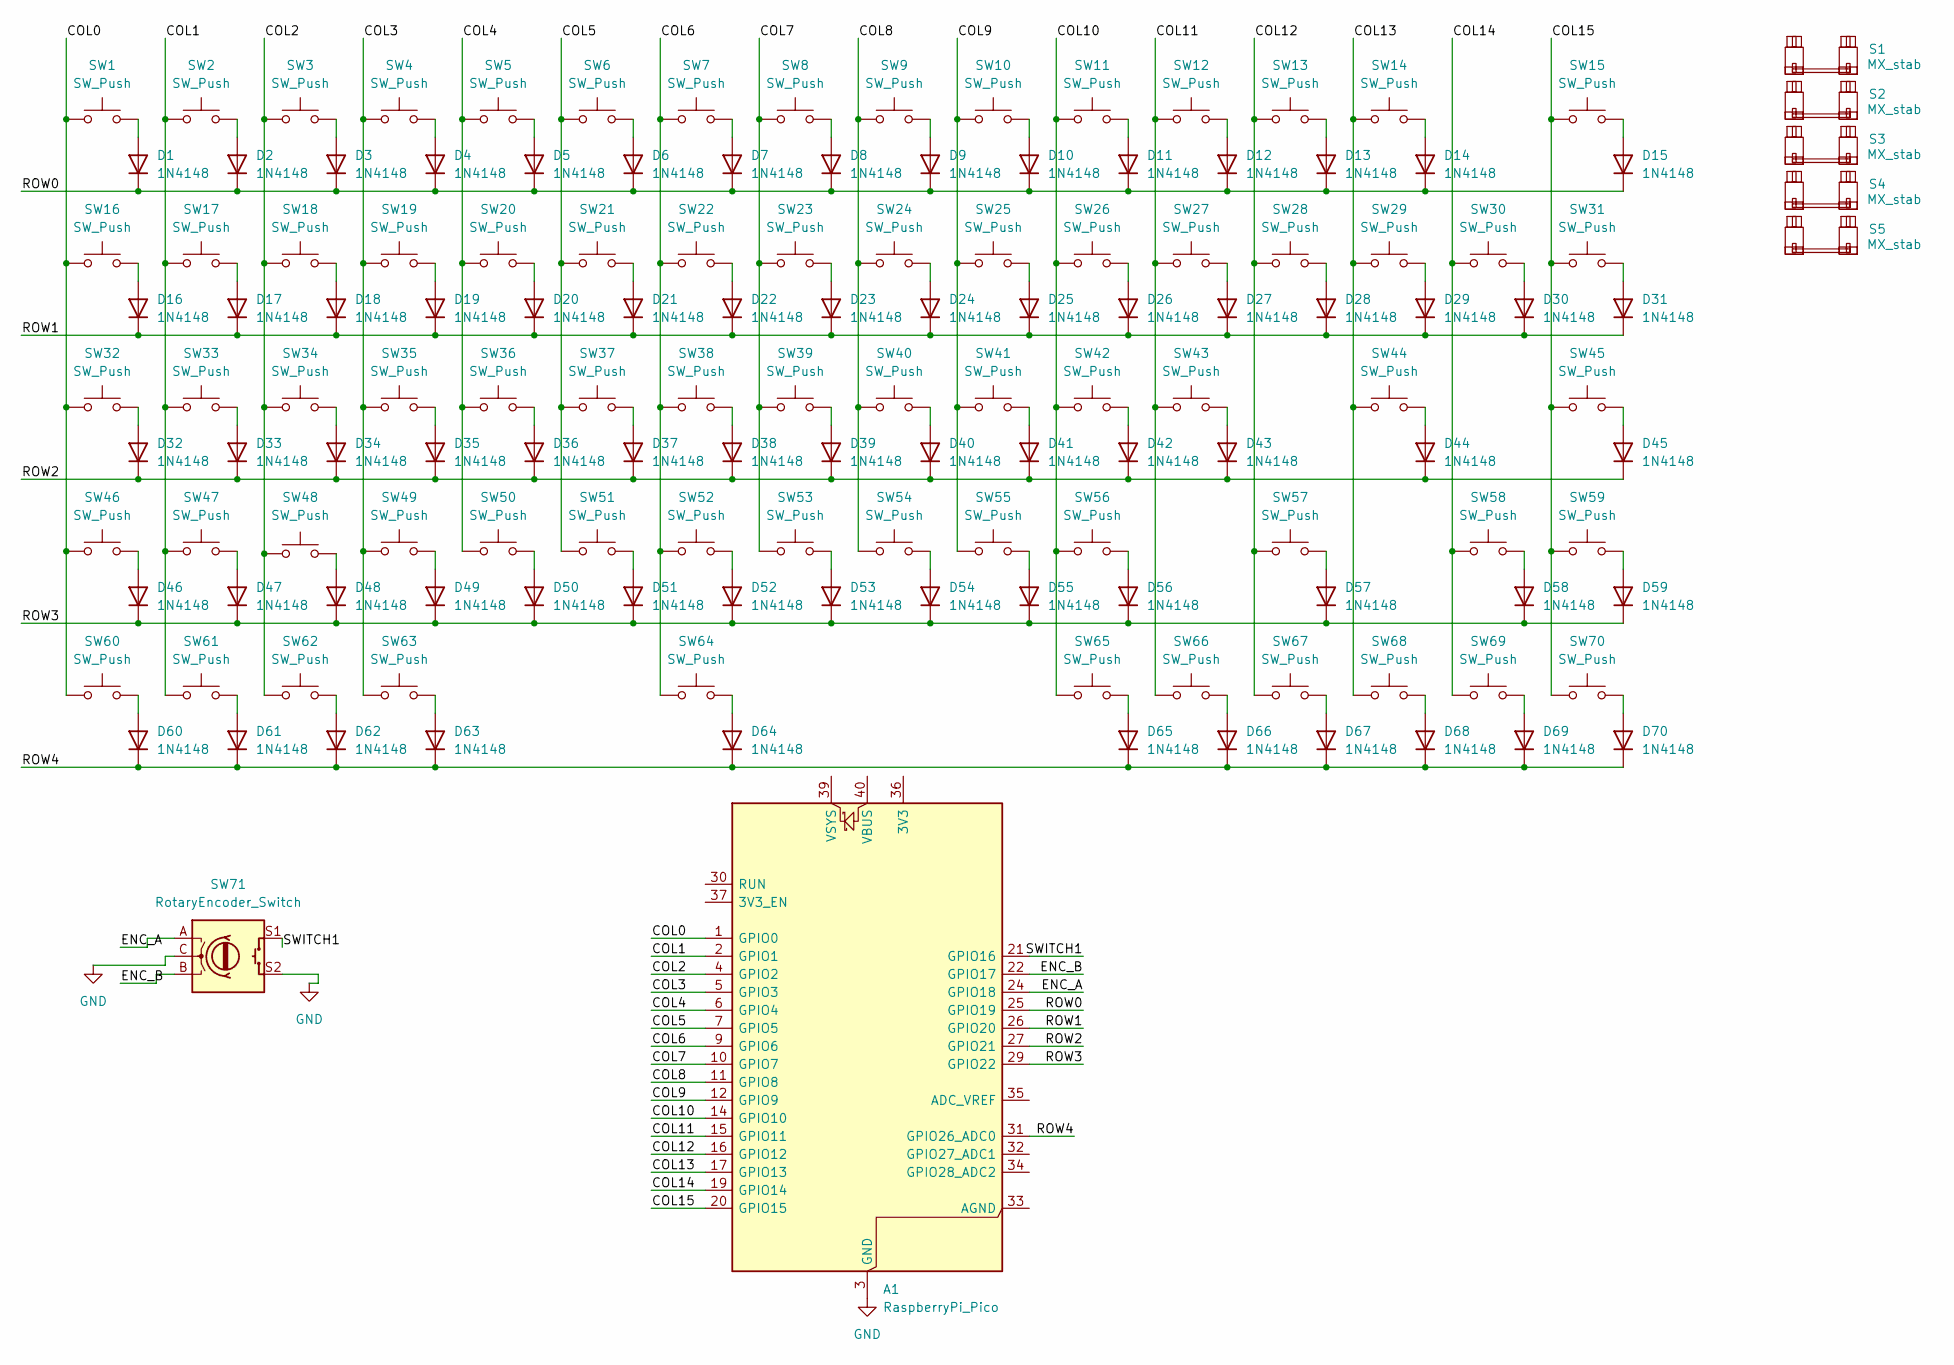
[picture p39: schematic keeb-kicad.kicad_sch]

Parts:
A1: RaspberryPi_Pico; RaspberryPi_Pico_Common_THT
D1, D2, D3, D4, D5, D6, D7, D8, D9, D10, D11, D12, D13, D14, D15, D16, D17, D18, D19, D20, D21, D22, D23, D24, D25, D26, D27, D28, D29, D30, D31, D32, D33, D34, D35, D36, D37, D38, D39, D40, D41, D42, D43, D44, D45, D46, D47, D48, D49, D50, D51, D52, D53, D54, D55, D56, D57, D58, D59, D60, D61, D62, D63, D64, D65, D66, D67, D68, D69, D70: 1N4148; D_DO-35_SOD27_P7.62mm_Horizontal
S1, S2: MX_stab; STAB_MX_P_2.75u
S3: MX_stab; STAB_MX_P_2u
S4: MX_stab; STAB_MX_P_3u
S5: MX_stab; STAB_MX_P_6.25u
SW1, SW2, SW3, SW4, SW5, SW6, SW7, SW8, SW9, SW10, SW11, SW12, SW13, SW14, SW15, SW16, SW17, SW18, SW19, SW20, SW21, SW22, SW23, SW24, SW25, SW26, SW27, SW28, SW29, SW30, SW31, SW32, SW33, SW34, SW35, SW36, SW37, SW38, SW39, SW40, SW41, SW42, SW43, SW44, SW45, SW46, SW47, SW48, SW49, SW50, SW51, SW52, SW53, SW54, SW55, SW56, SW57, SW58, SW59, SW60, SW61, SW62, SW63, SW64, SW65, SW66, SW67, SW68, SW69, SW70: SW_Push; SW_MX_1u
SW71: RotaryEncoder_Switch; RotaryEncoder_Alps_EC11E-Switch_Vertical_H20mm

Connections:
/COL0: A1.1 (GPIO0), SW1.1, SW16.1, SW32.1, SW46.1, SW60.1
/COL1: A1.2 (GPIO1), SW2.1, SW17.1, SW33.1, SW47.1, SW61.1
/COL2: A1.4 (GPIO2), SW3.1, SW18.1, SW34.1, SW48.1, SW62.1
/COL3: A1.5 (GPIO3), SW4.1, SW19.1, SW35.1, SW49.1, SW63.1
/COL4: A1.6 (GPIO4), SW5.1, SW20.1, SW36.1, SW50.1
/COL5: A1.7 (GPIO5), SW6.1, SW21.1, SW37.1, SW51.1
/COL6: A1.9 (GPIO6), SW7.1, SW22.1, SW38.1, SW52.1, SW64.1
/COL7: A1.10 (GPIO7), SW8.1, SW23.1, SW39.1, SW53.1
/COL8: A1.11 (GPIO8), SW9.1, SW24.1, SW40.1, SW54.1
/COL9: A1.12 (GPIO9), SW10.1, SW25.1, SW41.1, SW55.1
/COL10: A1.14 (GPIO10), SW11.1, SW26.1, SW42.1, SW56.1, SW65.1
/COL11: A1.15 (GPIO11), SW12.1, SW27.1, SW43.1, SW66.1
/COL12: A1.16 (GPIO12), SW13.1, SW28.1, SW57.1, SW67.1
/COL13: A1.17 (GPIO13), SW14.1, SW29.1, SW44.1, SW68.1
/COL14: A1.19 (GPIO14), SW30.1, SW58.1, SW69.1
/COL15: A1.20 (GPIO15), SW15.1, SW31.1, SW45.1, SW59.1, SW70.1
/ENC_A: A1.24 (GPIO18), SW71.A
/ENC_B: A1.22 (GPIO17), SW71.B
/ROW0: A1.25 (GPIO19), D1.1 (K), D2.1 (K), D3.1 (K), D4.1 (K), D5.1 (K), D6.1 (K), D7.1 (K), D8.1 (K), D9.1 (K), D10.1 (K), D11.1 (K), D12.1 (K), D13.1 (K), D14.1 (K), D15.1 (K)
/ROW1: A1.26 (GPIO20), D16.1 (K), D17.1 (K), D18.1 (K), D19.1 (K), D20.1 (K), D21.1 (K), D22.1 (K), D23.1 (K), D24.1 (K), D25.1 (K), D26.1 (K), D27.1 (K), D28.1 (K), D29.1 (K), D30.1 (K), D31.1 (K)
/ROW2: A1.27 (GPIO21), D32.1 (K), D33.1 (K), D34.1 (K), D35.1 (K), D36.1 (K), D37.1 (K), D38.1 (K), D39.1 (K), D40.1 (K), D41.1 (K), D42.1 (K), D43.1 (K), D44.1 (K), D45.1 (K)
/ROW3: A1.29 (GPIO22), D46.1 (K), D47.1 (K), D48.1 (K), D49.1 (K), D50.1 (K), D51.1 (K), D52.1 (K), D53.1 (K), D54.1 (K), D55.1 (K), D56.1 (K), D57.1 (K), D58.1 (K), D59.1 (K)
/ROW4: A1.31 (GPIO26_ADC0), D60.1 (K), D61.1 (K), D62.1 (K), D63.1 (K), D64.1 (K), D65.1 (K), D66.1 (K), D67.1 (K), D68.1 (K), D69.1 (K), D70.1 (K)
/SWITCH1: A1.21 (GPIO16), SW71.S1
GND: A1.3 (GND), A1.8 (GND), A1.13 (GND), A1.18 (GND), A1.23 (GND), A1.28 (GND), A1.38 (GND), SW71.C, SW71.S2
unnamed: D1.2 (A), SW1.2
unnamed: D2.2 (A), SW2.2
unnamed: D3.2 (A), SW3.2
unnamed: D4.2 (A), SW4.2
unnamed: D5.2 (A), SW5.2
unnamed: D6.2 (A), SW6.2
unnamed: D7.2 (A), SW7.2
unnamed: D8.2 (A), SW8.2
unnamed: D9.2 (A), SW9.2
unnamed: D10.2 (A), SW10.2
unnamed: D11.2 (A), SW11.2
unnamed: D12.2 (A), SW12.2
unnamed: D13.2 (A), SW13.2
unnamed: D14.2 (A), SW14.2
unnamed: D15.2 (A), SW15.2
unnamed: D16.2 (A), SW16.2
unnamed: D17.2 (A), SW17.2
unnamed: D18.2 (A), SW18.2
unnamed: D19.2 (A), SW19.2
unnamed: D20.2 (A), SW20.2
unnamed: D21.2 (A), SW21.2
unnamed: D22.2 (A), SW22.2
unnamed: D23.2 (A), SW23.2
unnamed: D24.2 (A), SW24.2
unnamed: D25.2 (A), SW25.2
unnamed: D26.2 (A), SW26.2
unnamed: D27.2 (A), SW27.2
unnamed: D28.2 (A), SW28.2
unnamed: D29.2 (A), SW29.2
unnamed: D30.2 (A), SW30.2
unnamed: D31.2 (A), SW31.2
unnamed: D32.2 (A), SW32.2
unnamed: D33.2 (A), SW33.2
unnamed: D34.2 (A), SW34.2
unnamed: D35.2 (A), SW35.2
unnamed: D36.2 (A), SW36.2
unnamed: D37.2 (A), SW37.2
unnamed: D38.2 (A), SW38.2
unnamed: D39.2 (A), SW39.2
unnamed: D40.2 (A), SW40.2
unnamed: D41.2 (A), SW41.2
unnamed: D42.2 (A), SW42.2
unnamed: D43.2 (A), SW43.2
unnamed: D44.2 (A), SW44.2
unnamed: D45.2 (A), SW45.2
unnamed: D46.2 (A), SW46.2
unnamed: D47.2 (A), SW47.2
unnamed: D48.2 (A), SW48.2
unnamed: D49.2 (A), SW49.2
unnamed: D50.2 (A), SW50.2
unnamed: D51.2 (A), SW51.2
unnamed: D52.2 (A), SW52.2
unnamed: D53.2 (A), SW53.2
unnamed: D54.2 (A), SW54.2
unnamed: D55.2 (A), SW55.2
unnamed: D56.2 (A), SW56.2
unnamed: D57.2 (A), SW57.2
unnamed: D58.2 (A), SW58.2
unnamed: D59.2 (A), SW59.2
unnamed: D60.2 (A), SW60.2
unnamed: D61.2 (A), SW61.2
unnamed: D62.2 (A), SW62.2
unnamed: D63.2 (A), SW63.2
unnamed: D64.2 (A), SW64.2
unnamed: D65.2 (A), SW65.2
unnamed: D66.2 (A), SW66.2
unnamed: D67.2 (A), SW67.2
unnamed: D68.2 (A), SW68.2
unnamed: D69.2 (A), SW69.2
unnamed: D70.2 (A), SW70.2

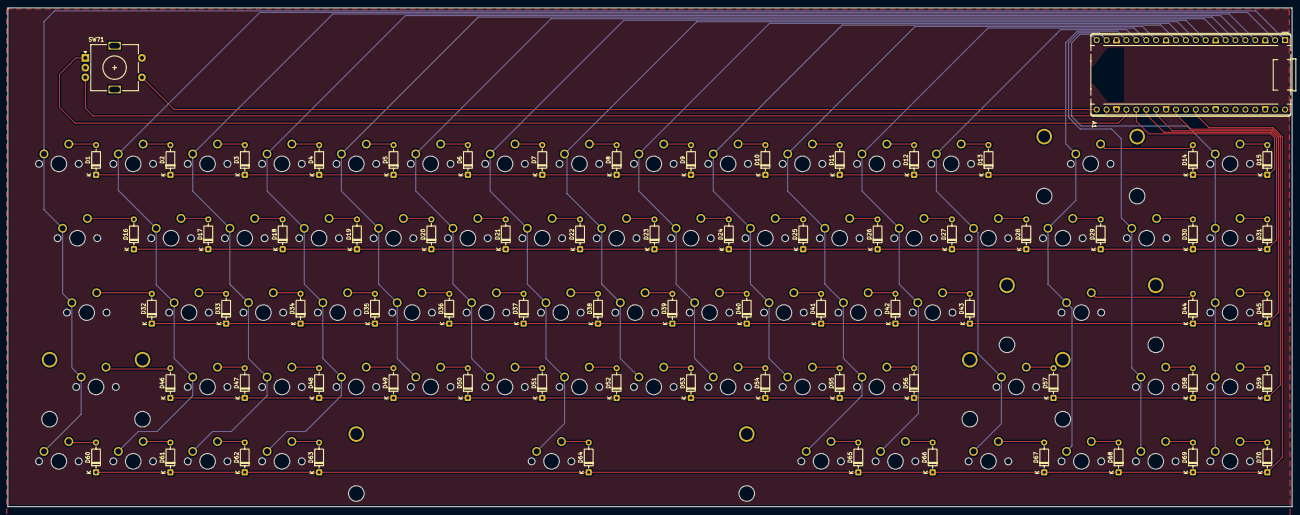
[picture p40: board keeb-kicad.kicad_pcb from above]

Board: 2 copper layers, 329.0 x 127.8 mm, 147 parts (0 on the bottom side), 95 nets.

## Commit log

2026-08-02 Planning stage journal entry with photos
2026-08-02 Setup KiCad files and libraries, and planned matrix onto keyboard
    [keeb-kicad.kicad_pcb, keeb-kicad.kicad_sch]
2026-08-02 Designed schematic replicating matrix and connecting rotary encoder
    [keeb-kicad.kicad_sch]
2026-08-02 Assigned footprints to all components
2026-08-03 Changed sizing of specific keys in keyboard, placed top two rows swtiches on pcb board
    [keeb-kicad.kicad_sch]
2026-08-03 Finished PCB assembly of keyboard switches
    [keeb-kicad.kicad_pcb, keeb-kicad.kicad_sch]
2026-08-03 Placed rest of the components onto PCB
    [keeb-kicad.kicad_pcb, keeb-kicad.kicad_sch]
2026-08-03 Added route tracing to front side of PCB
    [keeb-kicad.kicad_sch]
2026-08-03 Finished route tracing and added ground fill
    [keeb-kicad.kicad_pcb, keeb-kicad.kicad_sch]
2026-08-03 Resolved issues raised during DRC testing and compressed final files into zip
    [keeb-kicad-B_Cu.gbr, keeb-kicad-B_Mask.gbr, keeb-kicad-B_Paste.gbr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]
2026-08-03 Started work on the bottom part of case and repositioned switches to proper position
2026-08-04 Moved journal to seperate markdown file. Updated pcb with the 3d models.
    [keeb-kicad.kicad_pcb]
2026-08-04 Continued working on the bottom tray and finished up pcb 3d models with accurate EC11 and switch orientation/height
    [EC11 Rotary Encoder Dode Switch-15mm .STEP, Kailh Polia.step, keeb-kicad.kicad_pcb]
2026-08-04 Finished up plate part of case
2026-08-04 Continued working on case, made a better plate with a plate generator
2026-08-04 Added plate with switches and stabilizers cut out
2026-08-05 Finished up plate, added keycaps to render
    [keeb-kicad.kicad_pcb]
2026-08-05 Finished adding keycaps to assembly
2026-08-05 Finished keyboard top case and monting mechanism
2026-08-05 Added/refined small features in case design
2026-08-05 Added final STL files
    [knob.stl, left-bottom-tray.stl, left-plate.stl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]
2026-08-05 Added chamfers to PCB corners
2026-08-06 Worked on BOM, refined screw boss for compatability with actual hardware
2026-08-08 Updated schematic with new layout
2026-08-08 Updated PCB with layout
2026-08-10 Finished and exported PCB
2026-08-12 Cotninued working on case
2026-08-15 Fixed PCB left shift key and updated case
2026-08-17 Added more details to case
2026-08-19 Split case into 2 halves for printing
2026-08-19 Extruded plate up to edge of bottom case to allow for more support while keeping USB-C port accessible
2026-08-20 Organized repo folders, added full 3d models and step 3d models, and added new photos of the finished case
2026-08-20 Completed BOM and refined journal and README. Also added more images
